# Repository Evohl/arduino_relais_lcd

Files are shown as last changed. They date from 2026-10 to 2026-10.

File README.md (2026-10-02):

# Arduino Relay Controller with LCD

A local control panel for up to 32 relay channels. An Arduino Mega switches the relays, an LCD shows the commanded output states, and a rotary encoder provides local control. Channels can also be controlled over USB serial. The project does not require a network or cloud service.

There is no electrical feedback from the relay contacts. The display shows the state requested by the firmware, not whether a contact physically changed state.

## System Overview

```mermaid
flowchart LR
	operator[Operator] --> controller["RepRap Smart Controller 12864<br/>LCD, encoder, and pushbutton"]
	controller <-->|EXP1 / EXP2| mega["Arduino Mega 2560<br/>Control logic and EEPROM"]
	reset[Optional reset button] -->|Momentary contact: RESET to GND| mega
	computer[PC or host program] <-->|USB serial, 115200 baud| mega
	mega -->|D22-D37| board1["Relay board 1<br/>Channels 1-16"]
	mega -->|Optional: D38-D53| board2["Relay board 2<br/>Channels 17-32"]
	supply[Separate supply rated for the relay board] --> board1
	supply --> board2
	board1 --> load1[Connected loads]
	board2 --> load2[Connected loads]
```

The Mega reads the encoder, updates the display, and drives the relay inputs. The active channel count and channel numbering base are stored in EEPROM. One 16-channel relay board is needed for a 16-channel setup; a second board is optional for 32 channels.

## Components

| Component | Purpose |
| --- | --- |
| Arduino Mega 2560 | Controls the display, input, and up to 32 relay outputs |
| RepRap Smart Controller 12864 (5 V, ST7920) | Combines the graphic LCD, rotary encoder, and pushbutton; a separate encoder is not needed |
| External reset pushbutton (optional) | Resets the Mega when connected between RESET and GND |
| One or two 16-channel relay boards | Switches the connected loads |
| Separate, correctly rated power supply | Powers the relay coils as specified by the board manufacturer |
| USB connection to a PC (optional) | Uploads firmware and provides 115200-baud serial control |

## What You Can Do

- Select, switch, and monitor individual channels using the rotary encoder and LCD.
- Choose 16 or 32 active channels; the setting persists across power cycles.
- Number channels from 0 or 1 to match an external control program.
- Run a relay test that turns all active channels on, then turns them off one at a time at one-second intervals.
- Control channels from a serial terminal or a host program over USB.

This project does not provide scheduling, sensor input, or network control. It is intended for manual or serial relay control.

## Hardware and Pinout

| Function | Mega pin |
| --- | ---: |
| Relays 1-8 | D22-D29 |
| Relays 9-16 | D30-D37 |
| Relays 17-24 | D38-D45 |
| Relays 25-32 | D46-D53 |
| Display beeper (EXP1 pin 1) | D8 |
| Display KILL button (EXP2 pin 8) | D5, switch to GND |
| Optional reset button | Mega RESET to GND |
| Smart Controller EXP1 / EXP2 | See wiring diagram below |

Connector orientation and signal assignments can vary between display revisions; use the pin numbers and labels on your exact module, not its apparent left-to-right orientation in a drawing. Your shown pinout labels EXP1 pins 3-5 as NC and pins 6-7 as DOGLCD_CS / DOGLCD_A0. The sketch currently uses the U8g2 ST7920 driver with display signals on Mega D11-D13, so its LCD wiring is not verified for this module. Do not connect LCD signals using the generic diagram until the display controller and driver wiring are confirmed. The shown EXP1 pin 8 is NC, not RESET. Use a separate normally-open button between Mega RESET and GND if a hardware reset button is needed; never connect RESET to 5 V.

```mermaid
flowchart LR
	subgraph smart[RepRap Smart Controller 12864]
		exp1[EXP1]
		exp2[EXP2]
	end
	subgraph mega[Arduino Mega 2560]
		v5[5V]
		gnd[GND]
		d2[D2]
		d3[D3]
		d4[D4]
		d5[D5]
		d8[D8]
	end
	exp1 -->|Pin 1 beeper| d8
	exp1 -->|Pin 2 encoder button| d4
	exp1 -->|Pin 9 GND| gnd
	exp1 -->|Pin 10 VCC| v5
	exp2 -->|Pin 3 encoder A / CLK| d2
	exp2 -->|Pin 5 encoder B / DT| d3
	exp2 -.->|Pin 8 KILL_PIN, switch to GND| d5
	exp2 -->|Pin 9 GND| gnd
```

The SD-card signals are not used. When present, the beeper connects to D8 and sounds on accepted encoder-button presses. The EXP2 KILL button connects to D5 and GND; pressing it turns all active relays on if any are off, or turns them all off if they are already on. This is not an emergency stop; use a separate hardware cutoff for the relay supply. See [doc/pinout_display](doc/pinout_display) for connector details and wiring notes.

## Operation

In the relay grid, turn the encoder to select a channel and press it briefly to toggle that relay. Hold the pushbutton for 5 seconds to open or close the menu. Turn the encoder to select a menu item and press briefly to change the channel count or numbering base, start the relay test, or return to the grid.

The relay test turns all active channels on, then turns off the next channel once per second. Pressing the button cancels the test and turns off the remaining channels. The channel count and numbering base are saved in EEPROM.

## Serial Commands

Use 115200 baud and send one command per line. With channel numbering starting at 1:

```text
1,2,12:ON
12:OFF
all:OFF
```

With numbering starting at 0, address channels `0` through `15` or `0` through `31`. `all:ON` turns on every channel enabled in EEPROM; `all:OFF` turns them off. Use `all:ON` only when the contacts are safely wired and the supply is rated for all relay coils.

## Build and Upload

PlatformIO installs U8g2 as configured in `platformio.ini`. The default profile is `mega16`:

```sh
pio run
pio run -e mega16
pio run -e mega32
pio run -e mega16 -t upload --upload-port /dev/ttyACM0
```

Both profiles build firmware for the same Arduino Mega 2560. `RELAY_COUNT` is only the default when no valid channel count is stored in EEPROM; otherwise, the saved menu setting takes precedence. In the Arduino IDE, install U8g2 and set `RELAY_COUNT` to `16` or `32` if needed.

## 3D-Printed Parts

The STL files are in `stl/`:

- `Arduino Relais box arduino.stl`
- `Arduino Relais box card.stl`
- `Arduino Relais box cover.stl`

For a 16-relay setup, print the card-box part once. For 32 relays, print `Arduino Relais box card.stl` twice and stack the two card-box modules together to accommodate both relay boards. The Arduino and cover parts are also available as separate STL files. Import the models into a slicer; material, orientation, and print settings depend on your printer.

## Safety

The firmware uses active-low relay inputs: LOW means ON and HIGH means OFF. Do not power relay coils from the Mega's 5 V pin; use a separate supply rated for the relay board. Check the trigger jumper and input circuit on your specific board before wiring it. Use mains voltage only with suitable insulation, fusing, an enclosure, and strain relief. Keep the relay contacts unloaded during initial tests whenever possible.

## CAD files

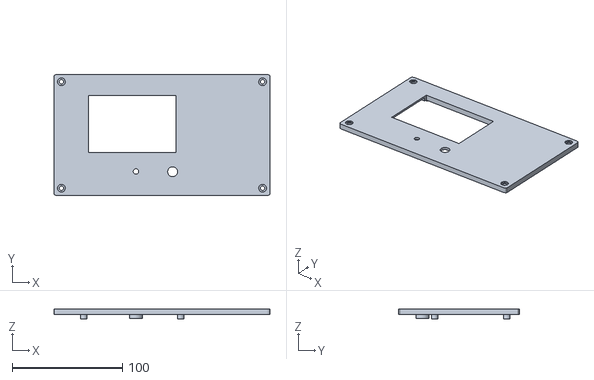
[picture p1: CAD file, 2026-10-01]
stl/Arduino Relais box arduino.stl
196.0 x 110.0 x 9.50

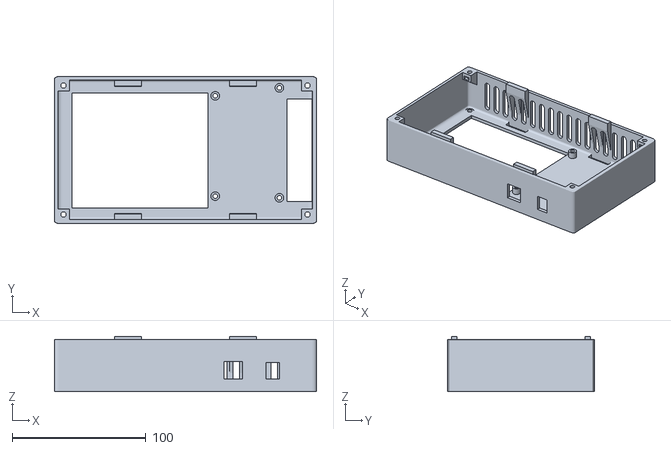
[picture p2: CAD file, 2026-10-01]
stl/Arduino Relais box cover.stl
196.0 x 110.0 x 41.5

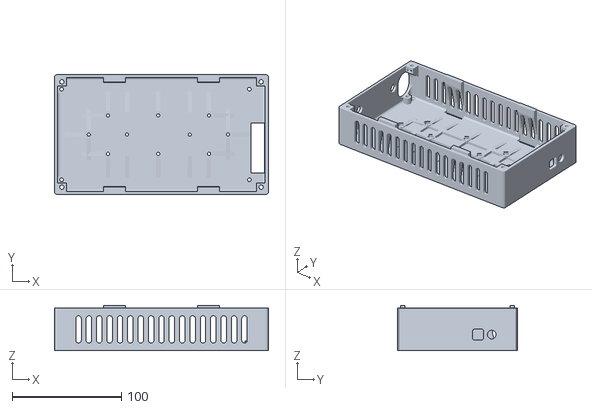
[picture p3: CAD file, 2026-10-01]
stl/Arduino Relais box card.stl
196.0 x 110.0 x 41.5

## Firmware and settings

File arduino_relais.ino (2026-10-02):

#include <U8g2lib.h>
#include <EEPROM.h>
#include <stdio.h>
#include <stdlib.h>
#include <string.h>

// Set to 16 for one 16-channel board or 32 for two boards.
#ifndef RELAY_COUNT
#define RELAY_COUNT 16
#endif

#if RELAY_COUNT != 16 && RELAY_COUNT != 32
#error "RELAY_COUNT must be 16 or 32"
#endif

const uint8_t relayPins[32] = {
    22, 23, 24, 25, 26, 27, 28, 29,
    30, 31, 32, 33, 34, 35, 36, 37,
    38, 39, 40, 41, 42, 43, 44, 45,
    46, 47, 48, 49, 50, 51, 52, 53
};

const uint8_t encoderA = 2;
const uint8_t encoderB = 3;
const uint8_t encoderButton = 4;
const uint8_t killInput = 5;
const uint8_t beeperPin = 8;
const uint8_t displayClock = 13;
const uint8_t displayData = 11;
const uint8_t displayCs = 12;

U8G2_ST7920_128X64_F_SW_SPI display(U8G2_R0, displayClock, displayData, displayCs, U8X8_PIN_NONE);

bool relayOn[32] = {};
uint8_t activeRelayCount = RELAY_COUNT;
uint8_t selectedRelay = 0;
uint8_t relayNumberBase = 1;
bool displayDirty = true;
bool menuActive = false;
uint8_t menuSelection = 0;
const uint8_t menuItemCount = 4;
bool relayTestActive = false;
uint8_t relayTestNext = 0;
unsigned long relayTestLastStepAt = 0;
const unsigned long relayTestIntervalMs = 1000;

volatile uint8_t encoderState = 0;
volatile int8_t encoderDelta = 0;
volatile unsigned long lastEncoderEdgeUs = 0;
const unsigned long encoderDebounceUs = 1000;
const int8_t encoderTransitions[16] = {
    0, -1, 1, 0,
    1, 0, 0, -1,
    -1, 0, 0, 1,
    0, 1, -1, 0
};
int8_t encoderRemainder = 0;

char serialLine[64];
uint8_t serialLength = 0;
bool serialOverflow = false;

bool buttonLastReading = HIGH;
bool buttonStableState = HIGH;
bool buttonLongPressHandled = false;
unsigned long buttonChangedAt = 0;
unsigned long buttonPressedAt = 0;
const unsigned long buttonDebounceMs = 35;
const unsigned long buttonLongPressMs = 5000;
bool killLastReading = HIGH;
bool killStableState = HIGH;
unsigned long killChangedAt = 0;
const unsigned long killDebounceMs = 35;

const uint8_t eepromRecordSize = 4;
const uint8_t eepromValidMarker = 0xA7;
int8_t activeEepromSlot = -1;
uint8_t eepromSequence = 0;
const int eepromRelayBaseAddress = 8;
const uint8_t eepromRelayBaseMarker = 0xB8;

void onEncoderChange() {
    const unsigned long now = micros();
    if (now - lastEncoderEdgeUs < encoderDebounceUs) {
        return;
    }
    lastEncoderEdgeUs = now;

    const uint8_t currentState = (digitalRead(encoderA) << 1) | digitalRead(encoderB);
    const uint8_t transition = (encoderState << 2) | currentState;
    const int8_t step = -encoderTransitions[transition];
    encoderState = currentState;

    if (step != 0) {
        if ((step > 0 && encoderDelta < 64) || (step < 0 && encoderDelta > -64)) {
            encoderDelta += step;
        }
    }
}

void beep() {
    tone(beeperPin, 2400, 35);
}

void toggleAllRelays() {
    bool allRelaysOn = true;
    for (uint8_t i = 0; i < activeRelayCount; i++) {
        if (!relayOn[i]) {
            allRelaysOn = false;
            break;
        }
    }

    const bool turnOn = !allRelaysOn;
    relayTestActive = false;
    for (uint8_t i = 0; i < activeRelayCount; i++) {
        setRelay(i, turnOn);
    }
    Serial.println(turnOn ? F("KILL switch: all relays ON") : F("KILL switch: all relays OFF"));
    beep();
}

void handleKillInput() {
    const unsigned long now = millis();
    const bool reading = digitalRead(killInput);

    if (reading != killLastReading) {
        killLastReading = reading;
        killChangedAt = now;
    }

    if (now - killChangedAt >= killDebounceMs && reading != killStableState) {
        killStableState = reading;
        if (killStableState == LOW) {
            toggleAllRelays();
        }
    }
}

bool readConfigRecord(uint8_t slot, uint8_t &relayCount, uint8_t &sequence) {
    const int address = slot * eepromRecordSize;
    const uint8_t marker = EEPROM.read(address);
    relayCount = EEPROM.read(address + 1);
    sequence = EEPROM.read(address + 2);
    const uint8_t checksum = EEPROM.read(address + 3);

    return marker == eepromValidMarker &&
        (relayCount == 16 || relayCount == 32) &&
        checksum == static_cast<uint8_t>(relayCount ^ sequence ^ 0x5A);
}

void loadRelayCount() {
    uint8_t count0;
    uint8_t sequence0;
    uint8_t count1;
    uint8_t sequence1;
    const bool valid0 = readConfigRecord(0, count0, sequence0);
    const bool valid1 = readConfigRecord(1, count1, sequence1);

    if (valid0 && valid1) {
        activeEepromSlot = static_cast<int8_t>(sequence0 - sequence1) > 0 ? 0 : 1;
    } else if (valid0) {
        activeEepromSlot = 0;
    } else if (valid1) {
        activeEepromSlot = 1;
    } else {
        activeRelayCount = RELAY_COUNT;
        activeEepromSlot = -1;
        eepromSequence = 0;
        return;
    }

    if (activeEepromSlot == 0) {
        activeRelayCount = count0;
        eepromSequence = sequence0;
    } else {
        activeRelayCount = count1;
        eepromSequence = sequence1;
    }
}

void saveRelayCount() {
    const uint8_t targetSlot = activeEepromSlot == 0 ? 1 : 0;
    const uint8_t nextSequence = eepromSequence + 1;
    const int address = targetSlot * eepromRecordSize;

    EEPROM.update(address, 0);
    EEPROM.update(address + 1, activeRelayCount);
    EEPROM.update(address + 2, nextSequence);
    EEPROM.update(address + 3, static_cast<uint8_t>(activeRelayCount ^ nextSequence ^ 0x5A));
    EEPROM.update(address, eepromValidMarker);

    activeEepromSlot = targetSlot;
    eepromSequence = nextSequence;
}

void loadRelayNumberBase() {
    const uint8_t marker = EEPROM.read(eepromRelayBaseAddress);
    const uint8_t storedBase = EEPROM.read(eepromRelayBaseAddress + 1);
    const uint8_t checksum = EEPROM.read(eepromRelayBaseAddress + 2);
    if (marker == eepromRelayBaseMarker && storedBase <= 1 &&
        checksum == static_cast<uint8_t>(storedBase ^ 0x5A)) {
        relayNumberBase = storedBase;
    }
}

void saveRelayNumberBase() {
    EEPROM.update(eepromRelayBaseAddress, 0);
    EEPROM.update(eepromRelayBaseAddress + 1, relayNumberBase);
    EEPROM.update(eepromRelayBaseAddress + 2, static_cast<uint8_t>(relayNumberBase ^ 0x5A));
    EEPROM.update(eepromRelayBaseAddress, eepromRelayBaseMarker);
}

void toggleRelayCount() {
    if (activeRelayCount == 32) {
        for (uint8_t i = 16; i < 32; i++) {
            digitalWrite(relayPins[i], HIGH);
            relayOn[i] = false;
        }
        activeRelayCount = 16;
    } else {
        activeRelayCount = 32;
    }

    if (selectedRelay >= activeRelayCount) {
        selectedRelay = 0;
    }
    encoderRemainder = 0;
    noInterrupts();
    encoderDelta = 0;
    interrupts();

    saveRelayCount();
    displayDirty = true;
    Serial.print(F("Relay count saved: "));
    Serial.println(activeRelayCount);
}

void toggleRelayNumberBase() {
    relayNumberBase = relayNumberBase == 0 ? 1 : 0;
    saveRelayNumberBase();
    displayDirty = true;
    Serial.print(F("Relay numbering starts at: "));
    Serial.println(relayNumberBase);
}

void setRelay(uint8_t relayIndex, bool turnOn) {
    relayOn[relayIndex] = turnOn;
    digitalWrite(relayPins[relayIndex], turnOn ? LOW : HIGH);
    Serial.print(F("OK: Relay "));
    Serial.print(relayIndex + relayNumberBase);
    Serial.println(turnOn ? F(" ON") : F(" OFF"));
    displayDirty = true;
}

void startRelayTest() {
    relayTestNext = 0;
    relayTestLastStepAt = millis();
    relayTestActive = true;
    for (uint8_t i = 0; i < activeRelayCount; i++) {
        setRelay(i, true);
    }
    Serial.println(F("Relay test started"));
}

void stopRelayTest() {
    if (!relayTestActive) {
        return;
    }
    relayTestActive = false;
    for (uint8_t i = 0; i < activeRelayCount; i++) {
        if (relayOn[i]) {
            setRelay(i, false);
        }
    }
    Serial.println(F("Relay test stopped"));
    displayDirty = true;
}

void drawMenu() {
    char labels[menuItemCount][20];
    snprintf(labels[0], sizeof(labels[0]), "Relais: %u", activeRelayCount);
    snprintf(labels[1], sizeof(labels[1]), "Start: %u", relayNumberBase);
    if (relayTestActive) {
        snprintf(labels[2], sizeof(labels[2]), "Test %u/%u", relayTestNext + relayNumberBase, activeRelayCount);
    } else {
        snprintf(labels[2], sizeof(labels[2]), "Relais-Test");
    }
    snprintf(labels[3], sizeof(labels[3]), "Zurueck");

    display.setFont(u8g2_font_5x7_tf);
    display.drawStr(2, 9, "Menue");
    for (uint8_t i = 0; i < menuItemCount; i++) {
        const uint8_t y = 19 + i * 12;
        display.drawStr(1, y, i == menuSelection ? ">" : " ");
        display.drawStr(9, y, labels[i]);
    }
}

void drawDisplay() {
    display.clearBuffer();
    if (menuActive) {
        drawMenu();
        display.sendBuffer();
        displayDirty = false;
        return;
    }

    const uint8_t columns = activeRelayCount == 16 ? 4 : 8;
    const uint8_t cellWidth = 128 / columns;
    const uint8_t cellHeight = 64 / 4;
    const bool compactLabels = activeRelayCount == 32;
    display.setFont(compactLabels ? u8g2_font_5x7_tf : u8g2_font_6x10_tf);

    for (uint8_t relayIndex = 0; relayIndex < activeRelayCount; relayIndex++) {
        const uint8_t column = relayIndex % columns;
        const uint8_t row = relayIndex / columns;
        const uint8_t x = column * cellWidth;
        const uint8_t y = row * cellHeight;
        if (relayOn[relayIndex]) {
            display.drawBox(x + 1, y + 1, cellWidth - 2, cellHeight - 3);
            display.setDrawColor(0);
        } else {
            display.drawFrame(x + 1, y + 1, cellWidth - 2, cellHeight - 3);
        }
        char label[5];
        if (compactLabels) {
            snprintf(label, sizeof(label), "%02u", relayIndex + relayNumberBase);
        } else {
            snprintf(label, sizeof(label), "R%02u", relayIndex + relayNumberBase);
        }
        const uint8_t labelWidth = compactLabels ? 10 : 18;
        const uint8_t textX = x + (cellWidth - labelWidth) / 2;
        display.drawStr(textX, y + 11, label);
        display.setDrawColor(1);

        if (relayIndex == selectedRelay) {
            display.drawHLine(x + cellWidth / 2 - 2, y + cellHeight - 1, 5);
        }
    }

    display.sendBuffer();
    displayDirty = false;
}

void handleEncoder() {
    int8_t movement;
    noInterrupts();
    movement = encoderDelta;
    encoderDelta = 0;
    interrupts();

    if (relayTestActive) {
        encoderRemainder = 0;
        return;
    }
    if (menuActive) {
        encoderRemainder += movement;
        while (encoderRemainder >= 4) {
            encoderRemainder -= 4;
            menuSelection = (menuSelection + 1) % menuItemCount;
            displayDirty = true;
        }
        while (encoderRemainder <= -4) {
            encoderRemainder += 4;
            menuSelection = (menuSelection + menuItemCount - 1) % menuItemCount;
            displayDirty = true;
        }
        return;
    }

    encoderRemainder += movement;
    while (encoderRemainder >= 4) {
        encoderRemainder -= 4;
        selectedRelay = (selectedRelay + 1) % activeRelayCount;
        displayDirty = true;
    }
    while (encoderRemainder <= -4) {
        encoderRemainder += 4;
        selectedRelay = (selectedRelay + activeRelayCount - 1) % activeRelayCount;
        displayDirty = true;
    }
}

void selectMenuItem() {
    switch (menuSelection) {
        case 0:
            toggleRelayCount();
            break;
        case 1:
            toggleRelayNumberBase();
            break;
        case 2:
            startRelayTest();
            break;
        default:
            menuActive = false;
            displayDirty = true;
            break;
    }
}

void handleButton() {
    const unsigned long now = millis();
    const bool reading = digitalRead(encoderButton);

    if (reading != buttonLastReading) {
        buttonLastReading = reading;
        buttonChangedAt = now;
    }

    if (now - buttonChangedAt >= buttonDebounceMs && reading != buttonStableState) {
        buttonStableState = reading;
        if (buttonStableState == LOW) {
            buttonPressedAt = now;
            buttonLongPressHandled = false;
        } else if (!buttonLongPressHandled) {
            if (relayTestActive) {
                stopRelayTest();
            } else if (menuActive) {
                selectMenuItem();
            } else {
                setRelay(selectedRelay, !relayOn[selectedRelay]);
            }
            beep();
        }
    }

    if (buttonStableState == LOW && !buttonLongPressHandled && now - buttonPressedAt >= buttonLongPressMs) {
        if (relayTestActive) {
            stopRelayTest();
        }
        menuActive = !menuActive;
        menuSelection = 0;
        encoderRemainder = 0;
        displayDirty = true;
        buttonLongPressHandled = true;
        beep();
    }
}

void handleRelayTest() {
    if (!relayTestActive) {
        return;
    }

    const unsigned long now = millis();
    if (now - relayTestLastStepAt < relayTestIntervalMs) {
        return;
    }

    setRelay(relayTestNext, false);
    relayTestNext++;
    relayTestLastStepAt = now;
    if (relayTestNext >= activeRelayCount) {
        relayTestActive = false;
        Serial.println(F("Relay test complete"));
    }
}

char *trimWhitespace(char *text) {
    while (*text == ' ' || *text == '\t') {
        text++;
    }

    char *end = text + strlen(text);
    while (end > text && (end[-1] == ' ' || end[-1] == '\t')) {
        *--end = '\0';
    }
    return text;
}

bool processCommand(char *line) {
    char *separator = strchr(line, ':');
    if (separator == NULL || strchr(separator + 1, ':') != NULL) {
        return false;
    }

    *separator = '\0';
    char *relayList = trimWhitespace(line);
    char *operation = trimWhitespace(separator + 1);
    if (relayList[0] == '\0') {
        return false;
    }
    const bool turnOn = strcmp(operation, "ON") == 0;
    if (!turnOn && strcmp(operation, "OFF") != 0) {
        return false;
    }

    bool requested[32] = {};
    if (strcmp(relayList, "all") == 0) {
        for (uint8_t i = 0; i < activeRelayCount; i++) {
            requested[i] = true;
        }
    } else {
        char *token = relayList;
        while (*token != '\0') {
            char *nextToken = strchr(token, ',');
            if (nextToken != NULL) {
                *nextToken = '\0';
            }

            token = trimWhitespace(token);
            char *end = NULL;
            const long relayNumber = strtol(token, &end, 10);
            const long firstRelayNumber = relayNumberBase;
            const long lastRelayNumber = firstRelayNumber + activeRelayCount - 1;
            if (token[0] == '\0' || *end != '\0' || relayNumber < firstRelayNumber || relayNumber > lastRelayNumber) {
                return false;
            }
            requested[relayNumber - firstRelayNumber] = true;

            if (nextToken == NULL) {
                break;
            }
            token = nextToken + 1;
            if (*token == '\0') {
                return false;
            }
        }
    }

    for (uint8_t i = 0; i < activeRelayCount; i++) {
        if (requested[i]) {
            setRelay(i, turnOn);
        }
    }
    Serial.println(F("DONE"));
    return true;
}

void handleSerial() {
    while (Serial.available() > 0) {
        const char character = static_cast<char>(Serial.read());
        if (character == '\r' || character == '\n') {
            if (serialOverflow) {
                Serial.println(F("ERROR: command too long"));
            } else if (serialLength > 0) {
                serialLine[serialLength] = '\0';
                if (!processCommand(serialLine)) {
                    Serial.println(F("ERROR: expected relay[,relay]:ON|OFF or all:ON|OFF"));
                }
            }
            serialLength = 0;
            serialOverflow = false;
        } else if (!serialOverflow) {
            if (serialLength < sizeof(serialLine) - 1) {
                serialLine[serialLength++] = character;
            } else {
                serialOverflow = true;
            }
        }
    }
}

void setup() {
    Serial.begin(115200);

    for (uint8_t i = 0; i < 32; i++) {
        digitalWrite(relayPins[i], HIGH);
        pinMode(relayPins[i], OUTPUT);
    }
    loadRelayCount();
    loadRelayNumberBase();

    pinMode(encoderA, INPUT_PULLUP);
    pinMode(encoderB, INPUT_PULLUP);
    pinMode(encoderButton, INPUT_PULLUP);
    pinMode(killInput, INPUT_PULLUP);
    pinMode(beeperPin, OUTPUT);
    encoderState = (digitalRead(encoderA) << 1) | digitalRead(encoderB);
    attachInterrupt(digitalPinToInterrupt(encoderA), onEncoderChange, CHANGE);
    attachInterrupt(digitalPinToInterrupt(encoderB), onEncoderChange, CHANGE);

    display.begin();
    displayDirty = true;
    drawDisplay();
    Serial.print(F("Ready. Relay numbers start at "));
    Serial.println(relayNumberBase);
}

void loop() {
    handleKillInput();
    handleEncoder();
    handleButton();
    handleSerial();
    handleRelayTest();

    if (displayDirty) {
        drawDisplay();
    }
}

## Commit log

2026-10-01 Initial commit: Arduino relay controller and STL models
    [Arduino Relais box arduino.stl, Arduino Relais box card.stl, Arduino Relais box cover.stl]
2026-10-01 docs: clarify Smart Controller wiring
